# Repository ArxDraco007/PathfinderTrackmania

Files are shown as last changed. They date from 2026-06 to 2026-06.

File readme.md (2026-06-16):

## Building a custom wireless TrackMania controller from scratch.

## Why did I make this project?
I started this as a cool starter project to test my understanding of hardware and electronics.
I wanted to make a controller solely dedicated to a game that is customizable and fully functional with the game. I chose TrackMania, it stuck to my heart, and I made this controller.
It is a split controller to make it ergonomic and handleable to play.

## Why does my project do?
It has movement and custom buttons, such as ak40, ak60, and ak80, which, when placed in calculated best locations, provide digital steering. On a keyboard, your keys are either "on" (100% steering) or "off" (0%). However, at high speeds or on certain surfaces, 100% steering can cause the car to slide out, lose grip, or slow down. Action Keys act like a limiter or a "virtual steering wheel" that holds the wheels at a precise angle.

## Zine - 
zine (2)

## PICTURES - 
pathfindeee
SnowPathfinder
DesertPathfinder



## Assembly Instructions?
Heat-press the brass inserts into the case and glue the magnets into place.
Screw the stabilizers into the PCB and mount the sliding switch to the case.
Solder the diodes and header pins to the Seeeduino and PCB.
Click switches into the plate, screw the plate to the case, and add keycaps.
Flash your ZMK firmware to the Seeeduino.
Repeat for the second half, pair them, and test your work.

## How to use it?
Just look at the control buttons and start playing! The WASD keys are on the left of the board, which correspond to the gas, left, brake, and right. The checkpoint and the reset buttons are below, and the AK40, AK60, and AK80 buttons, which control the full speed to 40, 60, and 80 percent. The AK60 is on the left. The AK40 and AK80 are on the right.

### BOM

| Name | Purpose | Quantity | Total Cost (USD) | Link | Distributor |
|:---|:---|---:|---:|:-----|:---|
| Custom PCB | The PCB to hold all the components | 10  | 7.00 | [Link](https://jlcpcb.com) | JLCPCB |
| Blank DSA Keycaps  | Keycaps on top of the cherry mx | 10 | 5.00 | [Link](https://meckeys.com/shop/accessories/keyboard-accessories/keycaps/blank-dsa-keycaps-1u/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) | meckeys |
| Cherry MX | The keys for the pathfinder | 1 | 5.00 | [Link](https://meckeys.com/shop/accessories/keyboard-accessories/key-switches/cherry-mx-rgb-switch/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) | meckeys |
| SEEED XIAO RP2040  | The main board | 1 | 8.00 | [Link](https://robocraze.com/products/seeed-studio-xiao-rp2040-development-board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) | Robocraze |
| **1.5V LED Bulbs** | Indication of Power and Drift. | 2 | 1 | [Link](https://www.amazon.in/UNIVERSAL-Multicolour-Yellow-Pieces-3v-3-2v/dp/B09RQRP81V/) | Amazon |
| M3x4 mm Brass Heat Set Threaded Round Insert Nut (25Pcs) | Metal screw threads to hold the plastic | 1 Pack | $4.00 | [View Product](https://robu.in/product/m3-x-4-mm-brass-heat-set-knurl-threaded-round-insert-nut-25-pcs/) | Robu |
| Total | | | 30.00 | | |

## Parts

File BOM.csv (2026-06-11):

Name | Purpose | Quantity | Total Cost (USD) | Link | Distributor
Custom PCB | The PCB to hold all the components | 10 | 7.00 | https://jlcpcb.com | JLCPCB
Blank DSA Keycaps | Keycaps on top of the cherry mx | 10 | 5.00 | https://meckeys.com/shop/accessories/keyboard-accessories/keycaps/blank-dsa-keycaps-1u/ | meckeys
Cherry MX | The keys for the pathfinder | 1 | 5.00 | https://meckeys.com/shop/accessories/keyboard-accessories/key-switches/cherry-mx-rgb-switch/ | meckeys
SEEED XIAO RP2040 | The main board | 1 | 8.00 | https://robocraze.com/products/seeed-studio-xiao-rp2040-development-board?variant=47742255562976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 | Robocraze
1.5V LED Bulbs | Indication of Power and Drift. | 2 | 1.00 | https://www.amazon.in/UNIVERSAL-Multicolour-Yellow-Pieces-3v-3-2v/dp/B09RQRP81V/ | Amazon
Total |  |  | 26.00

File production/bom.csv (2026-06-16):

Designator | Footprint | Quantity | Value | LCSC Part #
D1 | LEDRD254W57D500H1070 | 1 | POWER
D2 | LEDRD254W57D500H1070 | 1 | Drift
R1, R2 | R_Axial_DIN0204_L3.6mm_D1.6mm_P5.08mm_Horizontal | 2 | R
SW1 | SW_Cherry_MX_1.00u_PCB | 1 | GAS
SW2 | SW_Cherry_MX_1.00u_PCB | 1 | BRAKE
SW3 | SW_Cherry_MX_1.00u_PCB | 1 | LEFT
SW4 | SW_Cherry_MX_1.00u_PCB | 1 | RIGHT
SW5 | SW_Cherry_MX_1.00u_PCB | 1 | CHECKPOINT
SW6 | SW_Cherry_MX_1.00u_PCB | 1 | RESTART
SW7 | SW_Cherry_MX_1.00u_PCB | 1 | AK40
SW8 | SW_Cherry_MX_1.00u_PCB | 1 | AK60
SW9 | SW_Cherry_MX_1.00u_PCB | 1 | AK80
U2, U3 | XIAO-Generic-Hybrid-14P-2.54-21X17.8MM | 2 | XIAO-RP2040-DIP

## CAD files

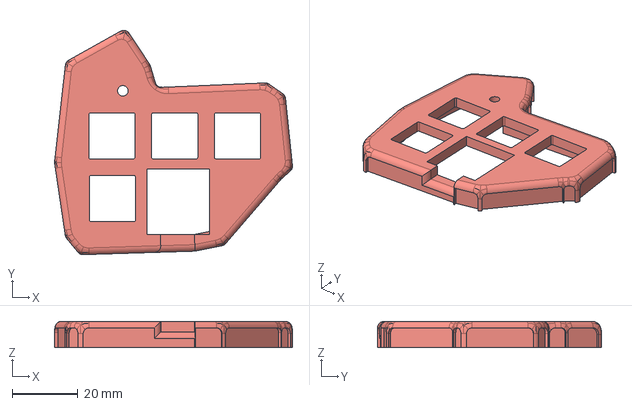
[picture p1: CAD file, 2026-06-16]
CAD/lefttop.step
72.2 x 68.0 x 8.00 mm

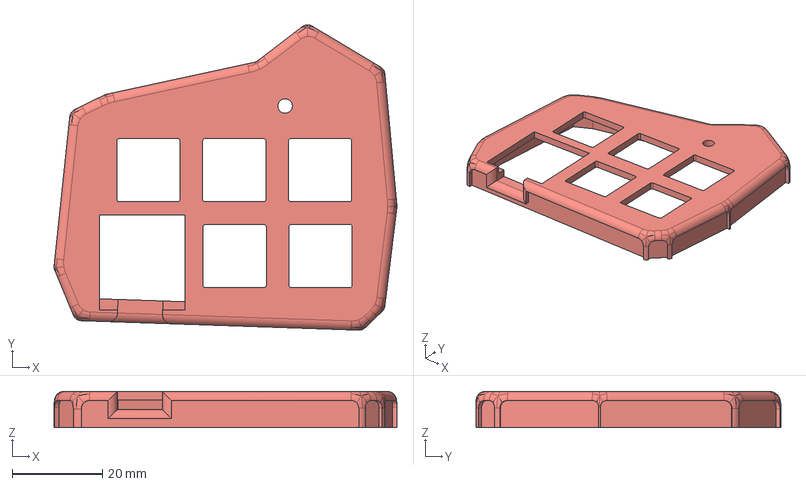
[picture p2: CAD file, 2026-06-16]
CAD/righttop.step
76.1 x 67.7 x 8.00 mm

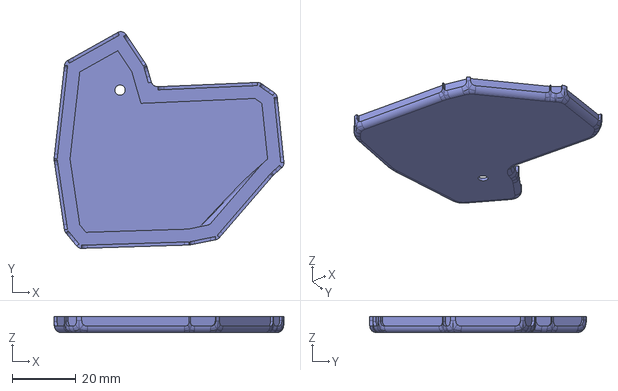
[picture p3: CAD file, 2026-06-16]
CAD/leftbottom.step
72.2 x 68.0 x 5.04 mm

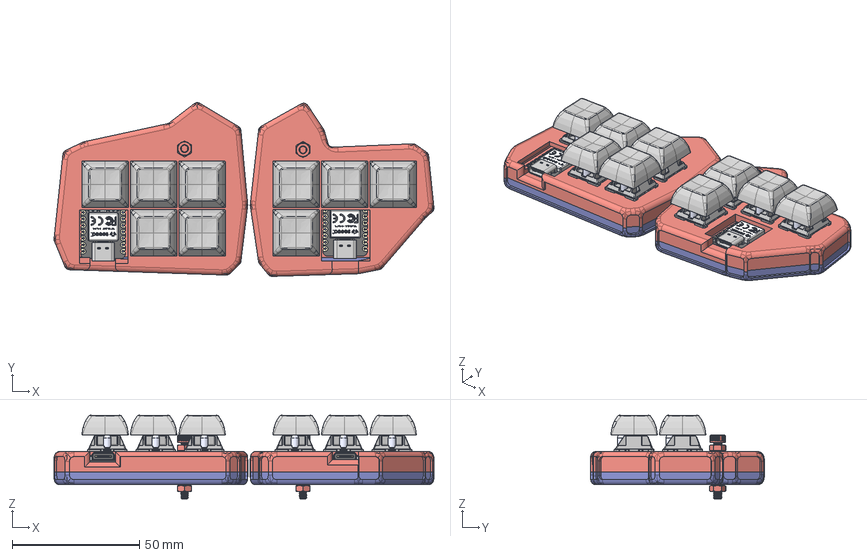
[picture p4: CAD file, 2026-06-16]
CAD/withholesPathfinder.step
149.2 x 68.3 x 32.8 mm
91290A124_Black-Oxide Alloy Steel Socket Head Screw x 2
90591A250_Zinc-Plated Steel Hex Nut x 4

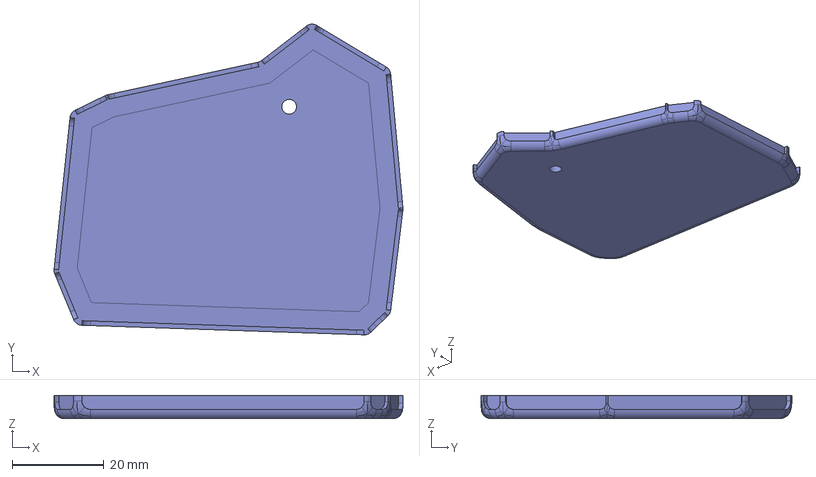
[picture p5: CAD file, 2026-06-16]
CAD/rightbottom.step
76.1 x 67.7 x 5.03 mm

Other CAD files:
CAD/assembly.f3z

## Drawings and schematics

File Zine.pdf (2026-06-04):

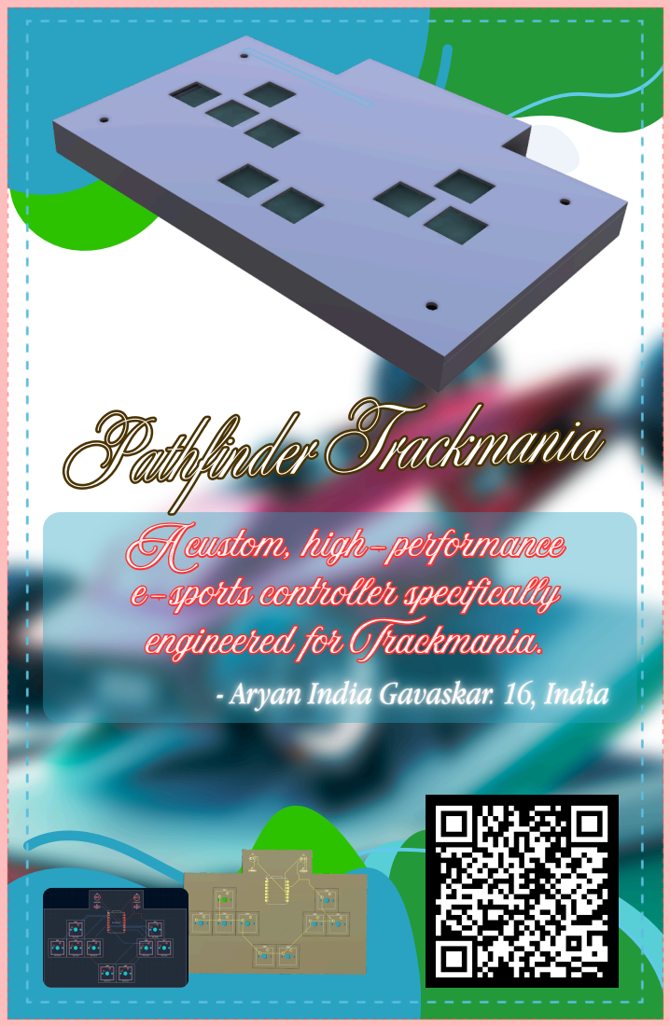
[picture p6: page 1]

PPathfinder Trackmania Pathfinder Trackmania athfinder Trackmania

A custom, high-performance
A custom, high-performance
e-sports controller specifically
e-sports controller specifically
engineered for Trackmania.
engineered for Trackmania.
- Aryan India Gavaskar. 16, India

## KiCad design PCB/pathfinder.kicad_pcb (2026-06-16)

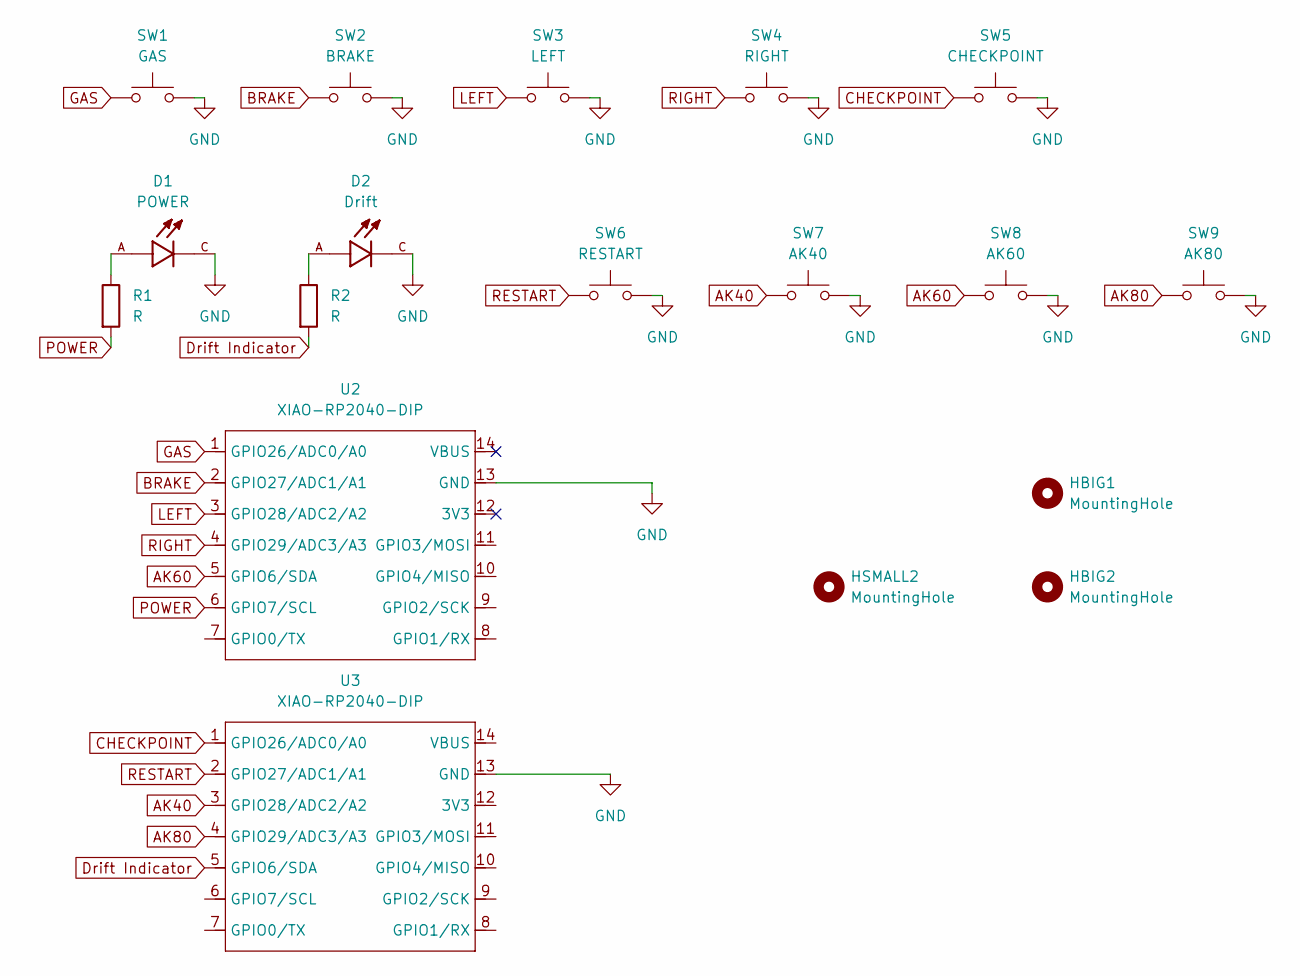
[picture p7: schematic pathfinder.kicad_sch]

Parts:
D1: POWER; LEDRD254W57D500H1070; PARTREV NA
D2: Drift; LEDRD254W57D500H1070; PARTREV NA
HBIG1, HBIG2: MountingHole; MountingHole_3.2mm_M3
HSMALL2: MountingHole; mouse-bite-2mm-slot
R1, R2: R; R_Axial_DIN0204_L3.6mm_D1.6mm_P5.08mm_Horizontal
SW1: GAS; SW_Cherry_MX_1.00u_PCB
SW2: BRAKE; SW_Cherry_MX_1.00u_PCB
SW3: LEFT; SW_Cherry_MX_1.00u_PCB
SW4: RIGHT; SW_Cherry_MX_1.00u_PCB
SW5: CHECKPOINT; SW_Cherry_MX_1.00u_PCB
SW6: RESTART; SW_Cherry_MX_1.00u_PCB
SW7: AK40; SW_Cherry_MX_1.00u_PCB
SW8: AK60; SW_Cherry_MX_1.00u_PCB
SW9: AK80; SW_Cherry_MX_1.00u_PCB
U2, U3: XIAO-RP2040-DIP; XIAO-Generic-Hybrid-14P-2.54-21X17.8MM

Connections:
AK40: SW7.1, U3.3 (GPIO28/ADC2/A2)
AK60: SW8.1, U2.5 (GPIO6/SDA)
AK80: SW9.1, U3.4 (GPIO29/ADC3/A3)
BRAKE: SW2.1, U2.2 (GPIO27/ADC1/A1)
CHECKPOINT: SW5.1, U3.1 (GPIO26/ADC0/A0)
Drift Indicator: R2.2, U3.5 (GPIO6/SDA)
GAS: SW1.1, U2.1 (GPIO26/ADC0/A0)
GND: D1.C, D2.C, SW1.2, SW2.2, SW3.2, SW4.2, SW5.2, SW6.2, SW7.2, SW8.2, SW9.2, U2.13 (GND), U3.13 (GND)
LEFT: SW3.1, U2.3 (GPIO28/ADC2/A2)
unnamed: D1.A, R1.1
unnamed: D2.A, R2.1
POWER: R1.2, U2.6 (GPIO7/SCL)
RESTART: SW6.1, U3.2 (GPIO27/ADC1/A1)
RIGHT: SW4.1, U2.4 (GPIO29/ADC3/A3)

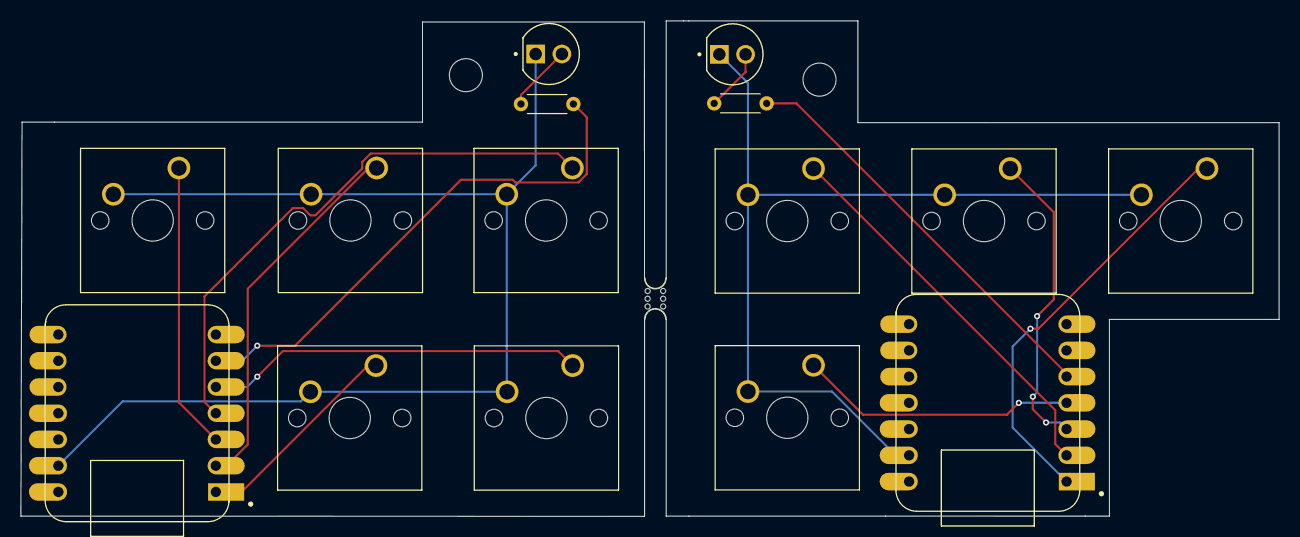
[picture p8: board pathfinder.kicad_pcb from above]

Board: 2 copper layers, 121.8 x 48.0 mm, 18 parts (0 on the bottom side), 14 nets.

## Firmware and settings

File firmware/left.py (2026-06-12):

import board
import digitalio
import usb_hid
import keypad
from adafruit_hid.keyboard import Keyboard
from adafruit_hid.keycode import Keycode

kbd = Keyboard(usb_hid.devices)

BUTTON_PINS = (
    board.D0,  # GAS    - GPIO26/A0
    board.D1,  # BRAKE  - GPIO27/A1
    board.D2,  # LEFT   - GPIO28/A2
    board.D3,  # RIGHT  - GPIO29/A3
    board.D4,  # AK60   - GPIO6/SDA
    board.D5,  # POWER  - GPIO7/SCL
)

KEYCODES = (
    Keycode.UP_ARROW,    # GAS
    Keycode.DOWN_ARROW,  # BRAKE
    Keycode.LEFT_ARROW,  # LEFT
    Keycode.RIGHT_ARROW, # RIGHT
    Keycode.THREE,       # AK60
    Keycode.ONE,         # POWER (set to your needed key)
)

keys = keypad.Keys(BUTTON_PINS, value_when_pressed=False, pull=True)

# POWER LED - always on, using a spare pin (e.g. D6 = GPIO3/MOSI on U2)
power_led = digitalio.DigitalInOut(board.D6)
power_led.direction = digitalio.Direction.OUTPUT
power_led.value = True

while True:
    event = keys.events.get()

    if event:
        key_idx = event.key_number

        if event.pressed:
            kbd.press(KEYCODES[key_idx])

        if event.released:
            kbd.release(KEYCODES[key_idx])

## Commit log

2026-04-17 PCB Design
    PCB Design
    [pathfinder.kicad_pcb, pathfinder.kicad_sch]
2026-04-17 Initialize README with project information
    Added project overview, pictures, and BOM details.
2026-05-01 Update Pathfinder - Trackmania-bom.csv
    [Pathfinder - Trackmania-bom.csv]
2026-06-01 Updates CAD
    [Case.stl, assembly.f3z, assembly.step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]
2026-06-04 Production Files
    [pathfinder-NPTH-drl_map.dxf, pathfinder-PTH-drl_map.dxf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]
2026-06-04 step files
    [Pathfinder.step, assembly.step]
2026-06-04 gerber and drill
    [pathfinder-NPTH-drl_map.dxf, pathfinder-PTH-drl_map.dxf, pathfinder.kicad_pcb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]
2026-06-05 CAD Changes
    [Case.stl, Pathfinder.step, assembly.f3z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]
2026-06-08 pcb change
    [pathfinder.kicad_pcb, pathfinder.kicad_sch]
2026-06-08 rotated the xiao
    [pathfinder.kicad_pcb]
2026-06-08 fusion acc to kicad
    [Pathfinder.step, assembly.f3z, bottom.stl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]
2026-06-12 gerber and pcb
    [Pathfinder.step, bottom.stl, leftbottom.step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]
2026-06-16 Revise readme with assembly instructions and images
    Updated the readme to include assembly instructions and additional images.
2026-06-16 prod, cad,
    [assembly.f3z, bom.csv, designators.csv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]
2026-09-18 Update readme with project details and assembly guide
